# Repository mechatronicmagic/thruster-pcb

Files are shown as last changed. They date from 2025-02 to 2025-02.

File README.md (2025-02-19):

- [Repository Info](#orgcf761ff)
- [Images](#orga1b146e)
- [Schematic](#org2f8730d)
- [PCB](#orgee0fed7)
- [Bill of Materials](#org8738594)
- [Development](#org028dfc6)

    <!-- This file is generated automatically from metadata -->
    <!-- File edits may be overwritten! -->

# Repository Info

-   Project Name: thruster-pcb
-   Synopsis:
-   Documentation Version: 1.0.0
-   Pcb Version: 1.0
-   Enclosure Version: 1.0
-   Supplemental BOM Version: 1.0
-   Release Date: 2025-02-19
-   Creation Date: 2025-01-04
-   Kicad Version: 7.0.11
-   License: GPL-3.0h
-   URL: <https://github.com/mechatronicmagic/thruster-pcb>
-   Author: Peter Polidoro
-   Email: peter@polidoro.io
-   Copyright: 2025 Mechatronic Magic
-   References:
    -   [Servo Control](https://en.wikipedia.org/wiki/Servo_control)
    -   [SB2264MG Servo](https://www.savoxusa.com/products/savsb2264mg-low-profile-hv-brushless-servo)
    -   [PCA9685](https://www.nxp.com/products/power-management/lighting-driver-and-controller-ics/led-drivers/16-channel-12-bit-pwm-fm-plus-ic-bus-led-driver:PCA9685)
    -   [nRF52840 Express](https://www.adafruit.com/product/4062)

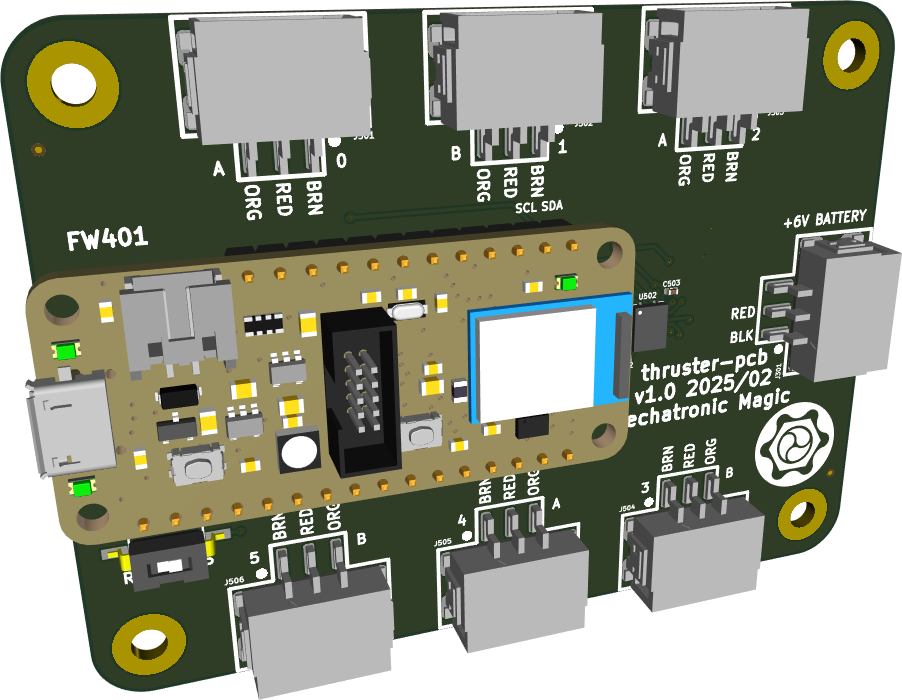
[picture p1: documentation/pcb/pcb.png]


# Images

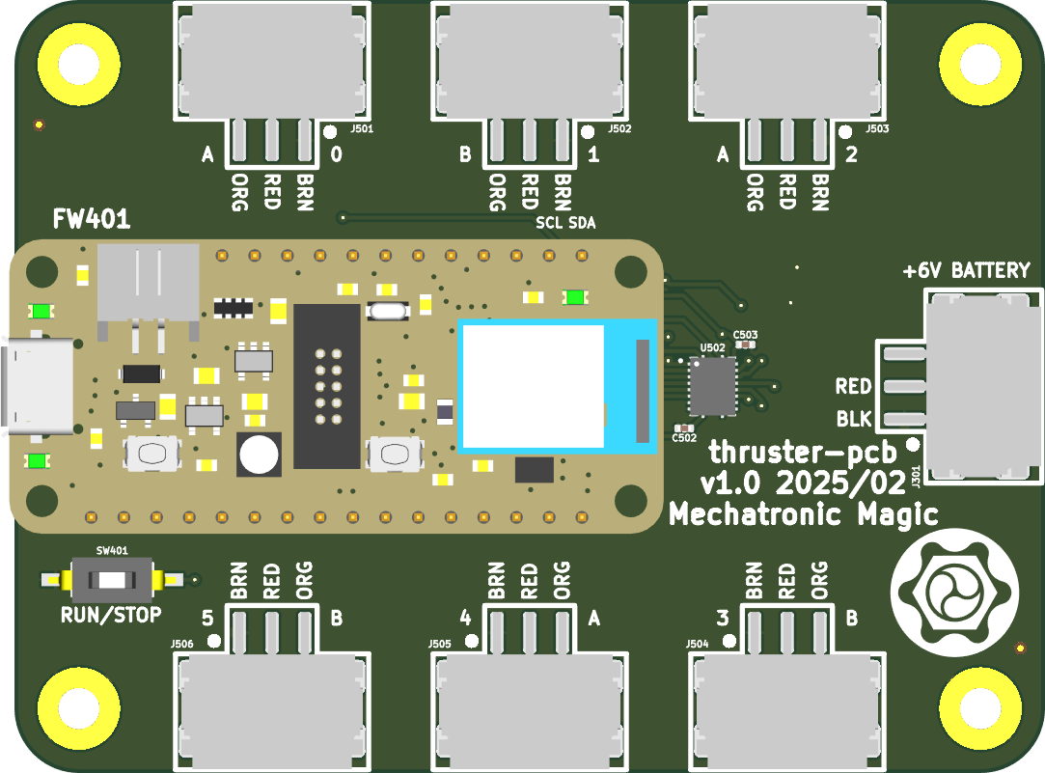
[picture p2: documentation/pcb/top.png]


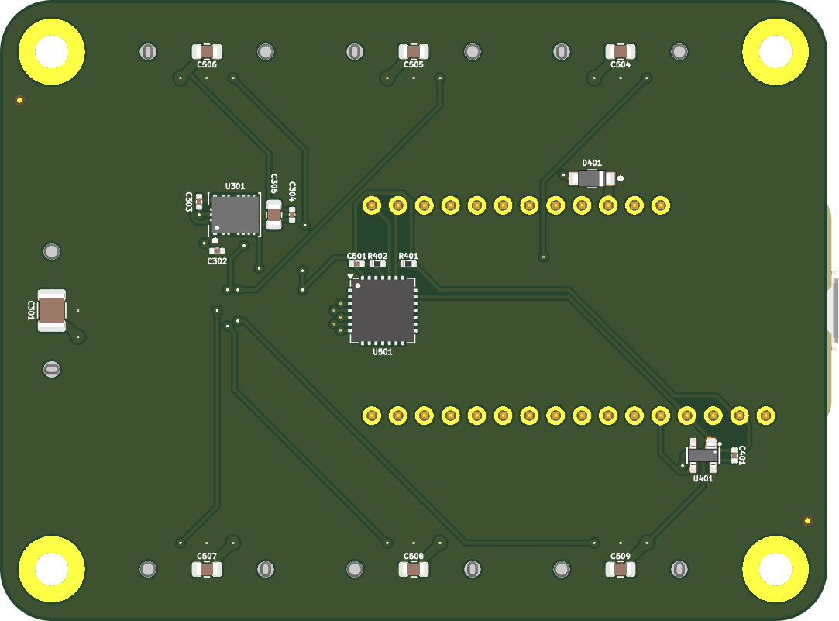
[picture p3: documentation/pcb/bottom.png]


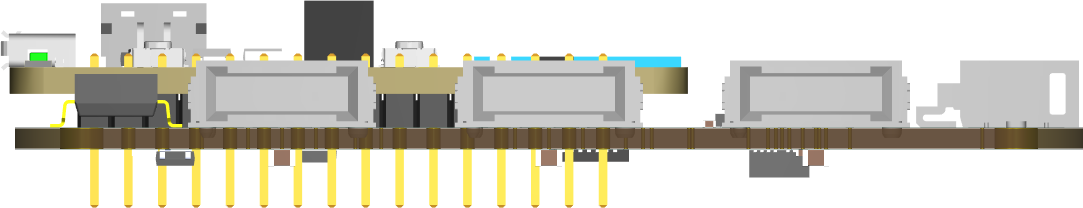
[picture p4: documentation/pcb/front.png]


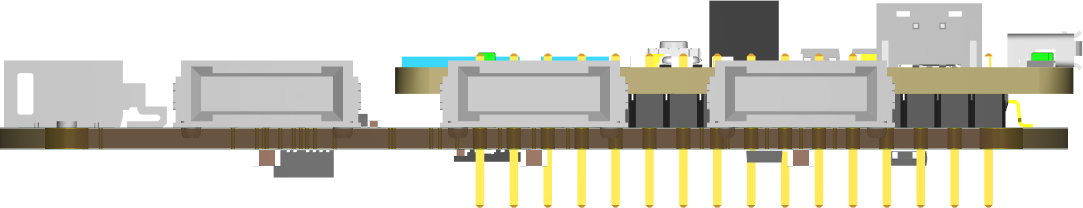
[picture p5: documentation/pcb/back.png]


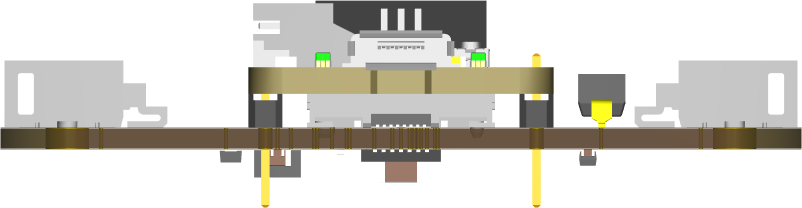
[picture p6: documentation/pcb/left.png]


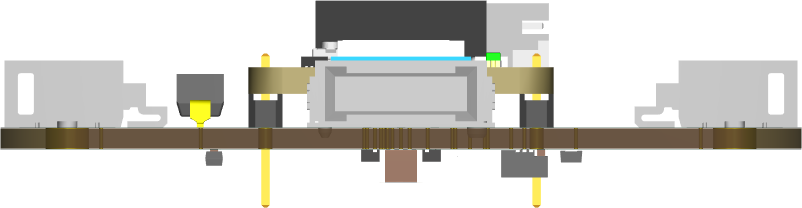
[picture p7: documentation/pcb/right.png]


# Schematic

[./documentation/schematic/thruster-pcb.pdf](./documentation/schematic/thruster-pcb.pdf)











# PCB











# Bill of Materials

## Board

| Item | Synopsis | Manufacturer Part Number | Manufacturer | Quantity | Reference(s) | Package |
|---- |--- |--- |--- |--- |--- |--- |
| 1 | 50V 3.3uF | FS32X335K500EGG | PSA(Prosperity Dielectrics) | 1 | C301 | 1210 |
| 2 | CAP CER 0.1UF 100V X5R | GRM155R62A104KE14D | Murata Electronics | 5 | C302 C401 C501 C502 C503 | 0402 |
| 3 | CAP CER 1UF 25V X5R | GRT155R61E105KE01D | Murata Electronics | 2 | C303 C304 | 0402 |
| 4 | CAP CER 47UF 10V X5R | CGA0805X5R476M100MT | HRE | 7 | C305 C504 C505 C506 C507 C508 C509 | 0805 |
| 5 | DIODE SCHOTTKY 20V 1A | MBR120VLSFT1G | onsemi | 1 | D401 | SOD-123FL |
| 6 | MAXIBR M 03POS RA A SMT BK | 284052-E | TE Connectivity | 7 | J301 J501 J502 J503 J504 J505 J506 | |
| 7 | RES SMD 1.8K OHM 5% 100mW | ERJ2GEJ182X | PANASONIC | 2 | R401 R402 | 0402 |
| 8 | 1 Digit SPST 24V 25mA DIP | EM-01KP | Korean Hroparts Elec | 1 | SW401 | SMD,2.5x6mm |
| 9 | DC-DC 5V 600mA Output 3-65V Input | TPSM365R6V5RDNR | Texas Instruments | 1 | U301 | QFN-11(3.5x4.5) |
| 10 | IC SWITCH DEBOUNCER | MAX6816EUS+T | Analog Devices Inc./Maxim Integrated | 1 | U401 | SOT-143 |
| 11 | IC LED DRVR LIN PWM 25MA | PCA9685BS,118 | NXP Semicon | 1 | U501 | SOT-788-1 |
| 12 | IC TRANSLTR BIDIRECTIONAL | TXS0108ERGYR | Texas Instruments | 1 | U502 | VQFN-20-EP(3.7x4.7) |

## Supplemental

| Item | Synopsis | Manufacturer Part Number | Manufacturer | Quantity | Cost  | Total |
|---- |--- |--- |--- |--- |----- |----- |
| 1 | Adafruit Feather nRF52840 Express | 4062 | adafruit | 1 | 24.95 | 24.95 |
| 2 | NiMH Battery (6V, 2700mAh, 2-Pos TJC8 Power Connector [MH-FC], 6-1) | 3100-0006-0001 | servocity | 1 | 14.99 | 14.99 |
| | Supplemental BOM Version: 1.0 | | | | Total | 39.94 |

# Development

## Install Guix

[Install Guix](https://guix.gnu.org/manual/en/html_node/Binary-Installation.html)

## Generate Output from KiCad

### Remove previous versions

```sh
rm -rf ./documentation/3dmodels/* && rm -rf ./documentation/bom/* && rm -rf ./documentation/fabrication/* && rm -rf ./documentation/pcb/* && rm -rf ./documentation/schematic/*pcb
```

### Images

1.  3D Viewer

    Output directory: ../documentation/pcb
    
    -   pcb.png
    -   top.png
    -   bottom.png
    -   front.png
    -   back.png
    -   left.png
    -   right.png

2.  Trim

        make trimmed-images

3.  Schematic PDF

    File -> Plot
    
    Output directory: ../documentation/schematic
    
    Plot All Pages
    
    -   Output format PDF
    -   Page Size = Schematic size
    -   Plot drawing sheet
    -   Output mode = Color
    -   Color theme = KiCad Default
    -   Default line width = 0.006 in

4.  Schematic SVG

    File -> Plot
    
    Output directory: ../documentation/schematic
    
    Plot All Pages
    
    -   Output format SVG
    -   Page Size = Schematic size
    -   Plot drawing sheet
    -   Output mode = Color
    -   Color theme = Solarized Light
    -   Default line width = 0.012 in

5.  PCB SVG

    Add Edge.Cuts, holes, and dimensions to User.Drawings
    
    File -> Plot
    
    Output directory: ../documentation/pcb
    
    -   Plot format SVG
    -   Include Layers
        -   User.Drawings
        -   F.Silkscreen
        -   B.Silkscreen
        -   F.Fab
        -   B.Fab
    -   Plot on All Layers
        -   Edge.Cuts
    -   Plot footprint values
    -   Plot reference designators
    -   SVG Options
        -   Precision = 4
        -   Output mode = color
    
        make cropped-svg

### Fabrication Files

1.  Gerbers

    File -> Fabrication Outputs -> Gerbers (.gbr)
    
    Output directory: ../documentation/fabrication/gerbers
    
    Include Layers:
    
    -   F.Cu
    -   F.Paste
    -   F.Silks
    -   F.Mask
    -   F.Fab
    -   B.Cu
    -   B.Paste
    -   B.Silks
    -   B.Mask
    -   B.Fab
    -   Edge.Cuts - (contain the board outline/cutouts.)
    -   In1.Cu, In2.Cu … - (needed for 4/6 layer designs.)
    
    Options:
    
    -   Select Plot reference designators, otherwise designators will not appear on silkscreen layers.
    -   Select Check zone fills before plotting
    -   Select Use Protel filename extensions, this is recommended as JLCPCB prefers Protel filename extensions.
    -   Select Subtract soldermask from silkscreen, this ensures no silkscreen on pads.
    -   Coordinate format 4.6 unit mm

2.  Drill and Map Files

    Output directory: ../documentation/fabrication/gerbers
    
    Options:
    
    -   Excellon drill file format
    -   Check Use alternate drill mode for "Oval Holes Drill Mode".
    -   Check Absolute for "Drill Origin".
    -   Check Millimeters for "Drill Units".
    -   Check Decimal format for "Zeros Format".
    -   Gerber X2 map file format
    
    Zip gerber files
    
        zip ./documentation/fabrication/gerbers.zip ./documentation/fabrication/gerbers/*

3.  BOM

    Generate BOM from schematic editor using blank command line to create bom xml file.

4.  POS

    File -> Fabrication Outputs -> Component Placement (.pos)
    
    Output directory: ../documentation/fabrication/
    
    Settings:
    
    -   Format = CSV
    -   Units = Millimeters
    -   Files = Single file for board
    -   Do not use drill/place file origin
    
    Modify pos files:
    
    -   Ref -> Designator
    -   PosX -> Mid X
    -   PosY -> Mid Y
    -   Rot -> Rotation
    -   Side -> Layer

5.  Step

    File -> Export -> Step
    
    Output directory: ../documentation/3dmodels/pcb.step
    
    -   Drill/place file origin
    -   Overwrite old file
    -   Standard Board outline chaining tolerance

## Edit metadata.org

    make metadata-edits

## Tangle metadata.org

    make metadata

## Edit project

    make kicad-edits
    exit

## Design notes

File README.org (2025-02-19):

# This file is generated automatically from metadata
# File edits may be overwritten!
- Project Name: thruster-pcb
- Synopsis: 
- Documentation Version: 1.0.0
- Pcb Version: 1.0
- Enclosure Version: 1.0
- Supplemental BOM Version: 1.0
- Release Date: 2025-02-19
- Creation Date: 2025-01-04
- Kicad Version: 7.0.11
- License: GPL-3.0h
- URL: https://github.com/mechatronicmagic/thruster-pcb
- Author: Peter Polidoro
- Email: peter@polidoro.io
- Copyright: 2025 Mechatronic Magic
- References:
  - [[https://en.wikipedia.org/wiki/Servo_control][Servo Control]]
  - [[https://www.savoxusa.com/products/savsb2264mg-low-profile-hv-brushless-servo][SB2264MG Servo]]
  - [[https://www.nxp.com/products/power-management/lighting-driver-and-controller-ics/led-drivers/16-channel-12-bit-pwm-fm-plus-ic-bus-led-driver:PCA9685][PCA9685]]
  - [[https://www.adafruit.com/product/4062][nRF52840 Express]]



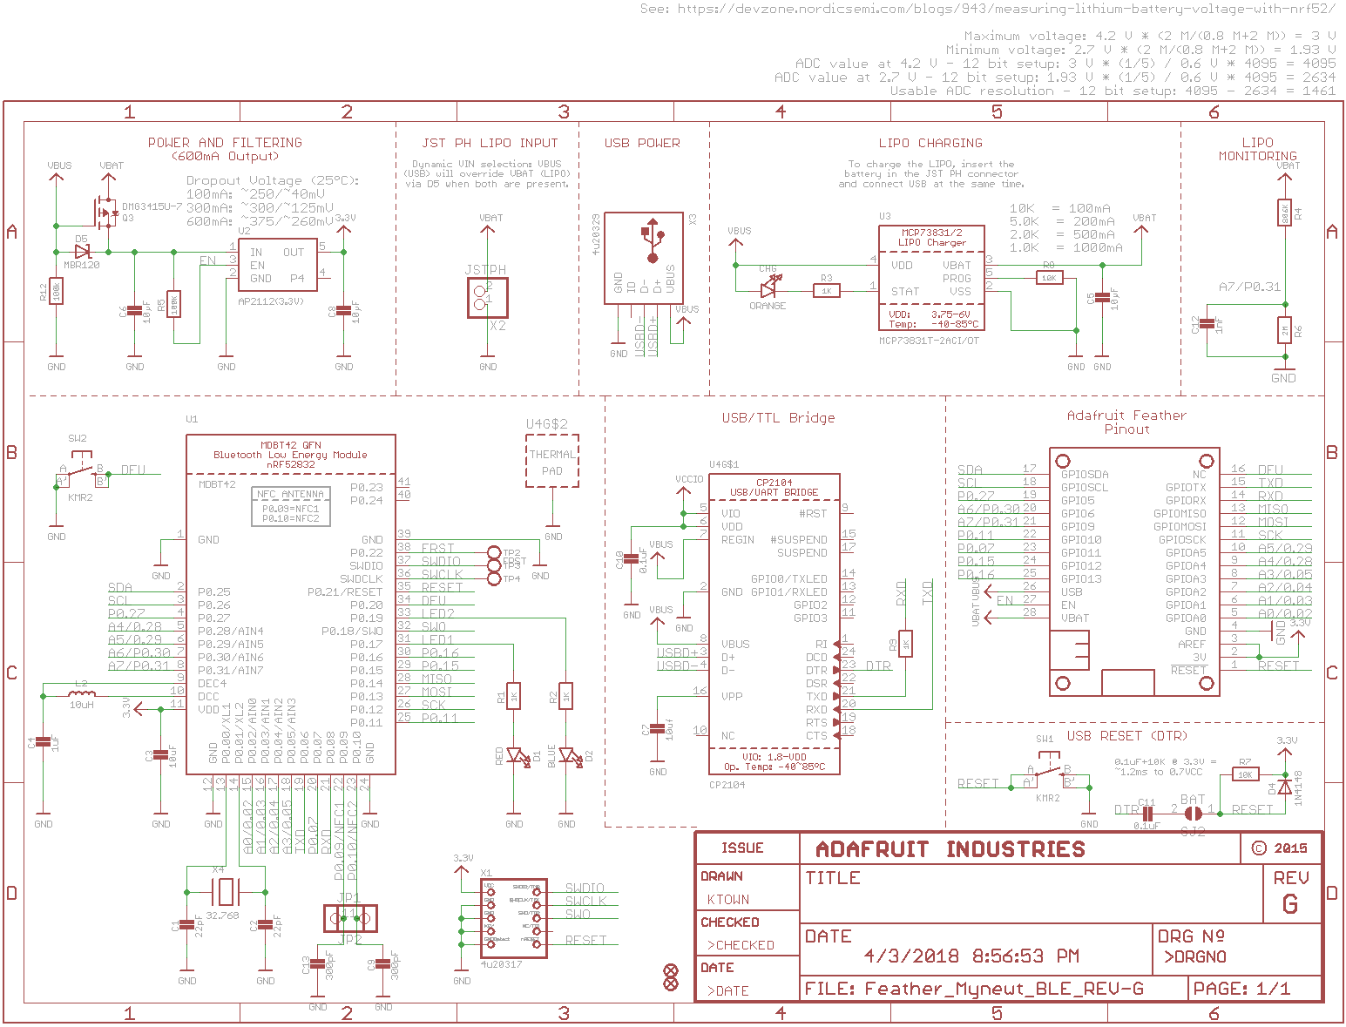
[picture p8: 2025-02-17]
documentation/reference/nrf52-schematic.png

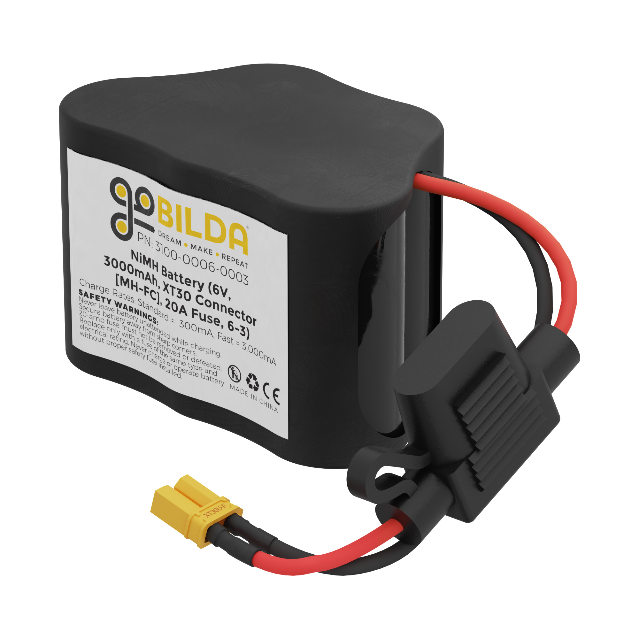
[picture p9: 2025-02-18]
documentation/reference/battery-xt30.jpg

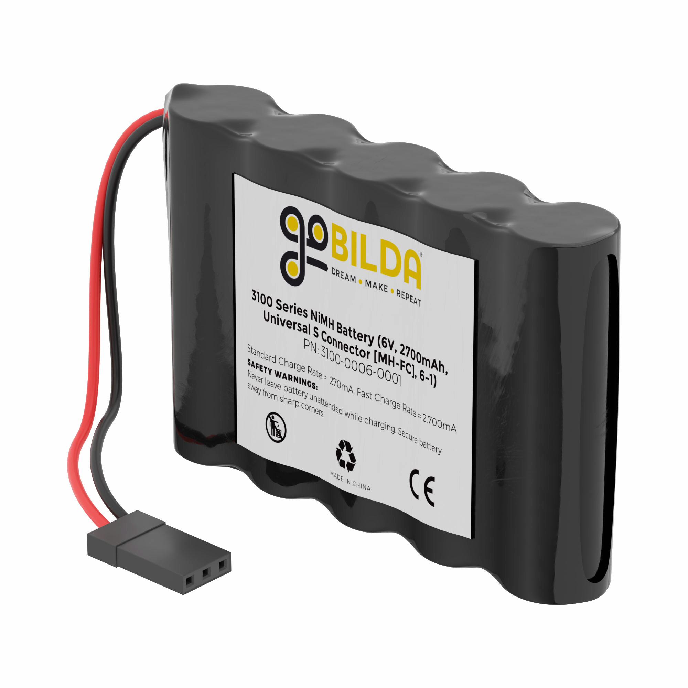
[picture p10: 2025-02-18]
documentation/reference/battery-tjc8.jpg

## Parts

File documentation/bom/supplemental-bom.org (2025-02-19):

#+OPTIONS: toc:nil title:nil num:nil ^:nil
#+LATEX_HEADER: \usepackage{adjustbox}
#+LATEX_HEADER: \usepackage[margin=2cm]{geometry}
* Supplemental BOM
- Project Name: thruster-pcb
- Synopsis: 
- Release Date: 2025-02-19
- URL: https://github.com/mechatronicmagic/thruster-pcb
- Author: Peter Polidoro
- Email: peter@polidoro.io
#+BEGIN_TABLE
#+LATEX: \adjustbox{max width=\linewidth}{
#+ATTR_LATEX: :center nil
| Item | Synopsis                                                            | Manufacturer Part Number | Manufacturer | Quantity |  Cost | Total |
|------+---------------------------------------------------------------------+--------------------------+--------------+----------+-------+-------|
|    1 | Adafruit Feather nRF52840 Express                                   |                     4062 | adafruit     |        1 | 24.95 | 24.95 |
|    2 | NiMH Battery (6V, 2700mAh, 2-Pos TJC8 Power Connector [MH-FC], 6-1) |           3100-0006-0001 | servocity    |        1 | 14.99 | 14.99 |
|------+---------------------------------------------------------------------+--------------------------+--------------+----------+-------+-------|
|      | Supplemental BOM Version: 1.0              |                          |              |          | Total | 39.94 |
#+TBLFM: @2$1..@>>$1=@#-1::$7=$5*$6;%0.2f::@>$7=vsum(@2..@-1);%0.2f
#+LATEX: }
#+END_TABLE

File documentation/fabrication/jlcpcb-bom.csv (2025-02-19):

Comment | Designator | Footprint | LCSC
50V 3.3uF | C301 | 1210 | C1021610
CAP CER 0.1UF 100V X5R | C302 C401 C501 C502 C503 | 0402 | C162178
CAP CER 1UF 25V X5R | C303 C304 | 0402 | C711085
CAP CER 47UF 10V X5R | C305 C504 C505 C506 C507 C508 C509 | 0805 | C6119904
DIODE SCHOTTKY 20V 1A | D401 | SOD-123FL | C223608
MAXIBR M 03POS RA A SMT BK | J301 J501 J502 J503 J504 J505 J506 |  | C17355078
RES SMD 1.8K OHM 5% 100mW | R401 R402 | 0402 | C409855
1 Digit SPST 24V 25mA DIP | SW401 | SMD,2.5x6mm | C129077
DC-DC 5V 600mA Output 3-65V Input | U301 | QFN-11(3.5x4.5) | C19078014
IC SWITCH DEBOUNCER | U401 | SOT-143 | C41637
IC LED DRVR LIN PWM 25MA | U501 | SOT-788-1 | C5191634
IC TRANSLTR BIDIRECTIONAL | U502 | VQFN-20-EP(3.7x4.7) | C90706

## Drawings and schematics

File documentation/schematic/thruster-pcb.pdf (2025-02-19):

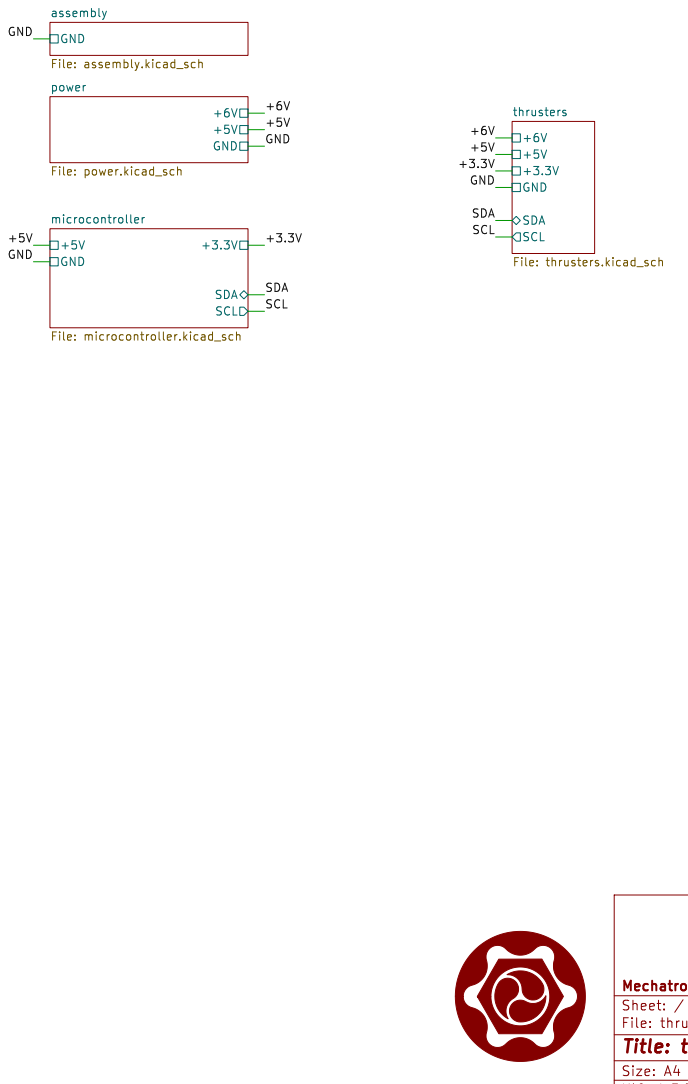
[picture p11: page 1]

power File: power.kicad_sch GND

Id: 1/5 Title: thruster-pcb

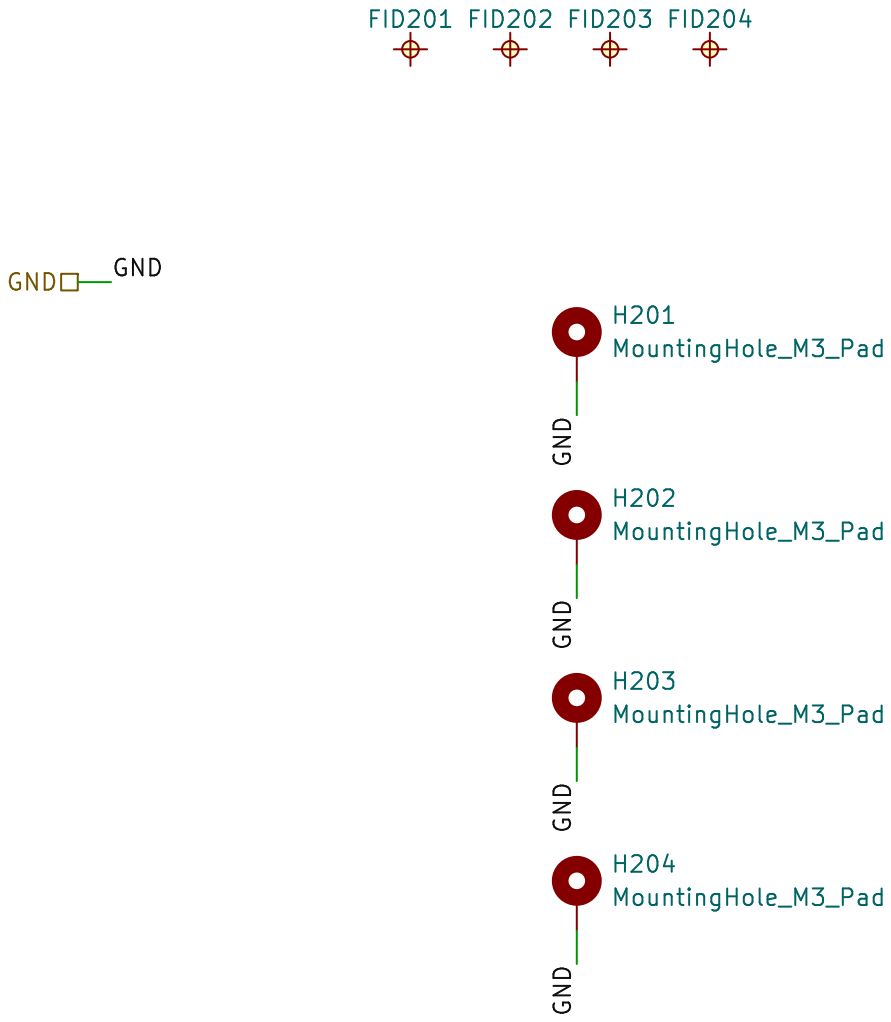
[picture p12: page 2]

Id: 2/5 Title: thruster-pcb

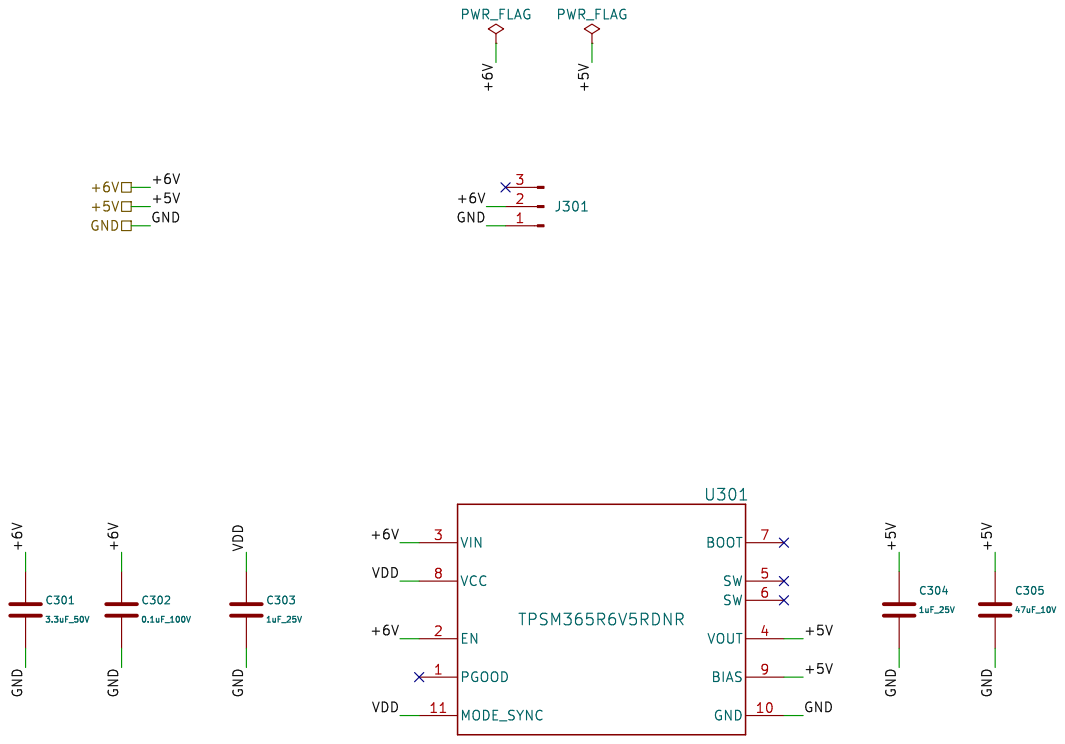
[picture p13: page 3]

Id: 3/5 Title: thruster-pcb

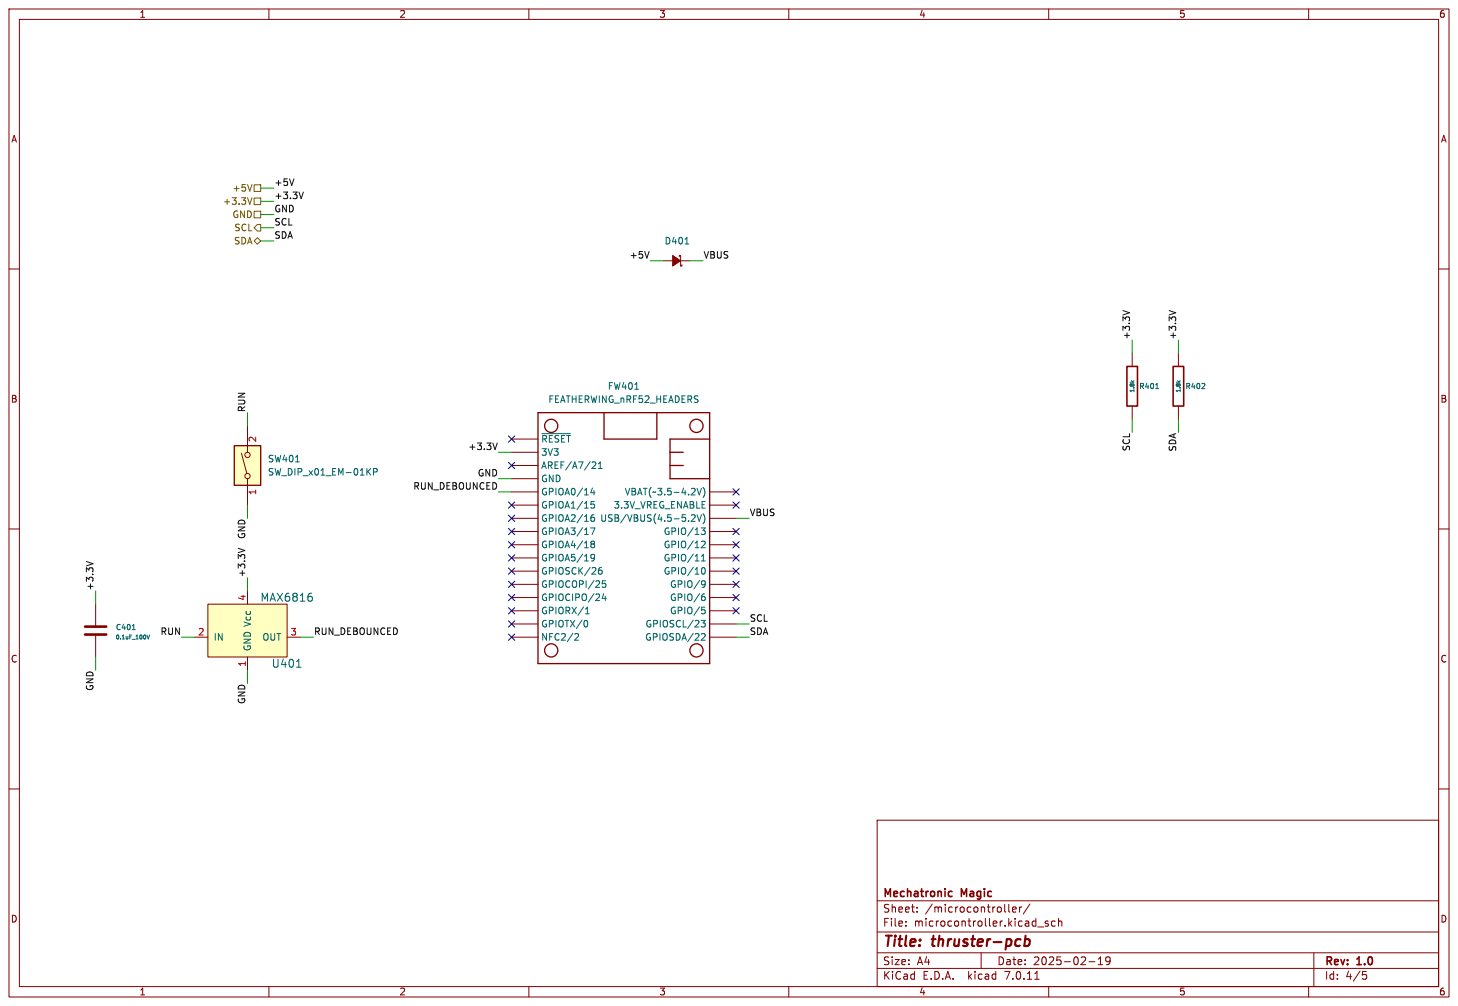
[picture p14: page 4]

Id: 4/5 Title: thruster-pcb

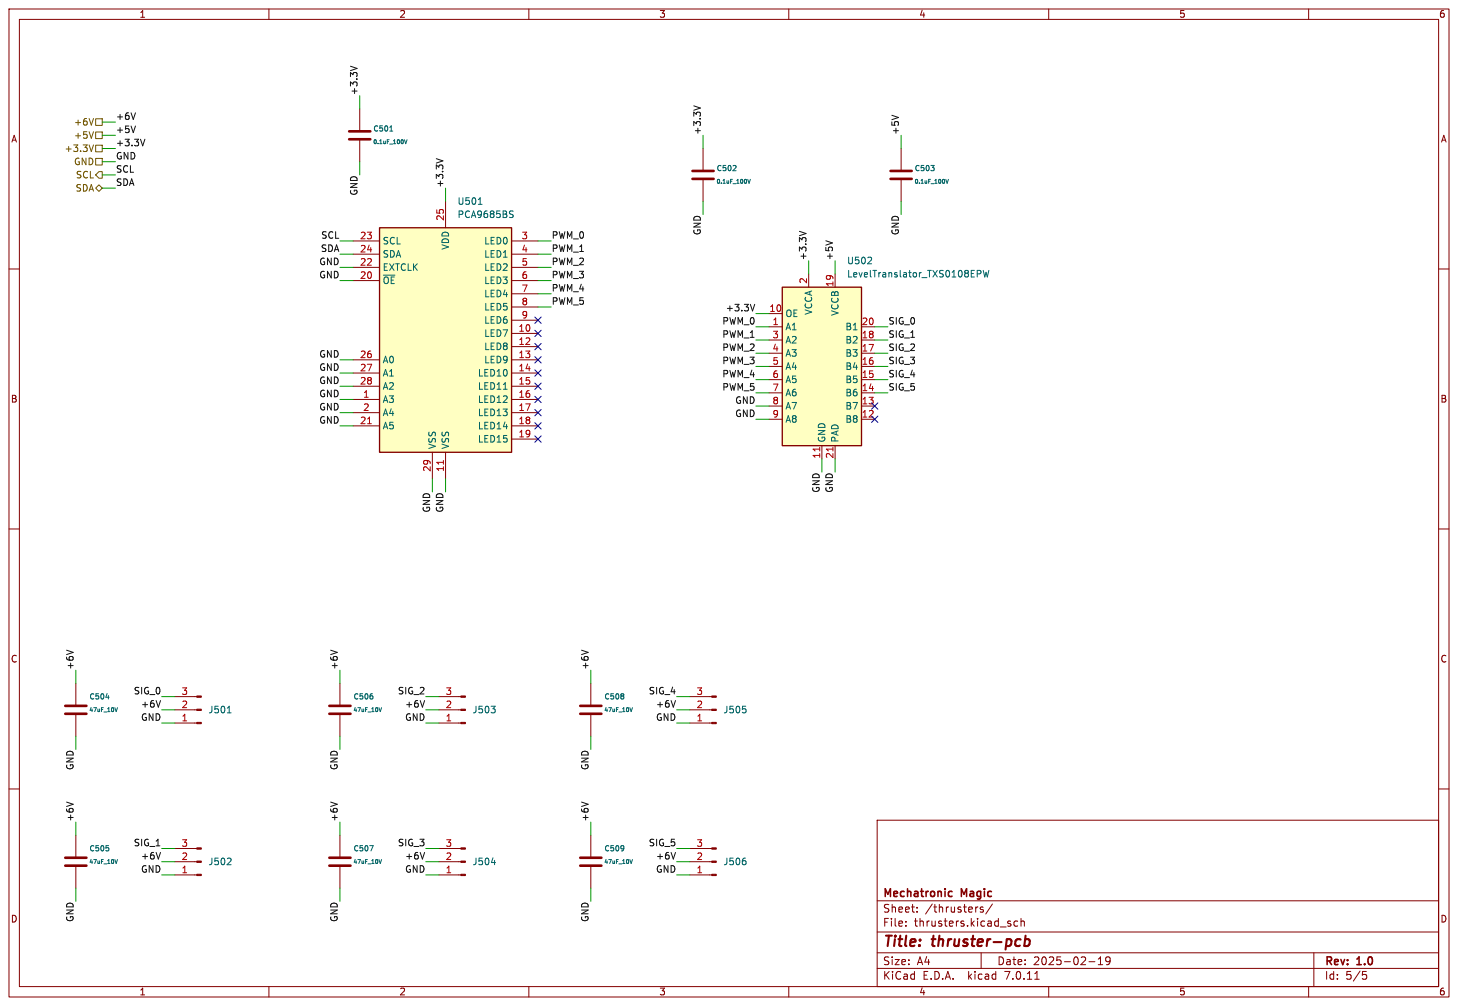
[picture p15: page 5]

Id: 5/5 Title: thruster-pcb

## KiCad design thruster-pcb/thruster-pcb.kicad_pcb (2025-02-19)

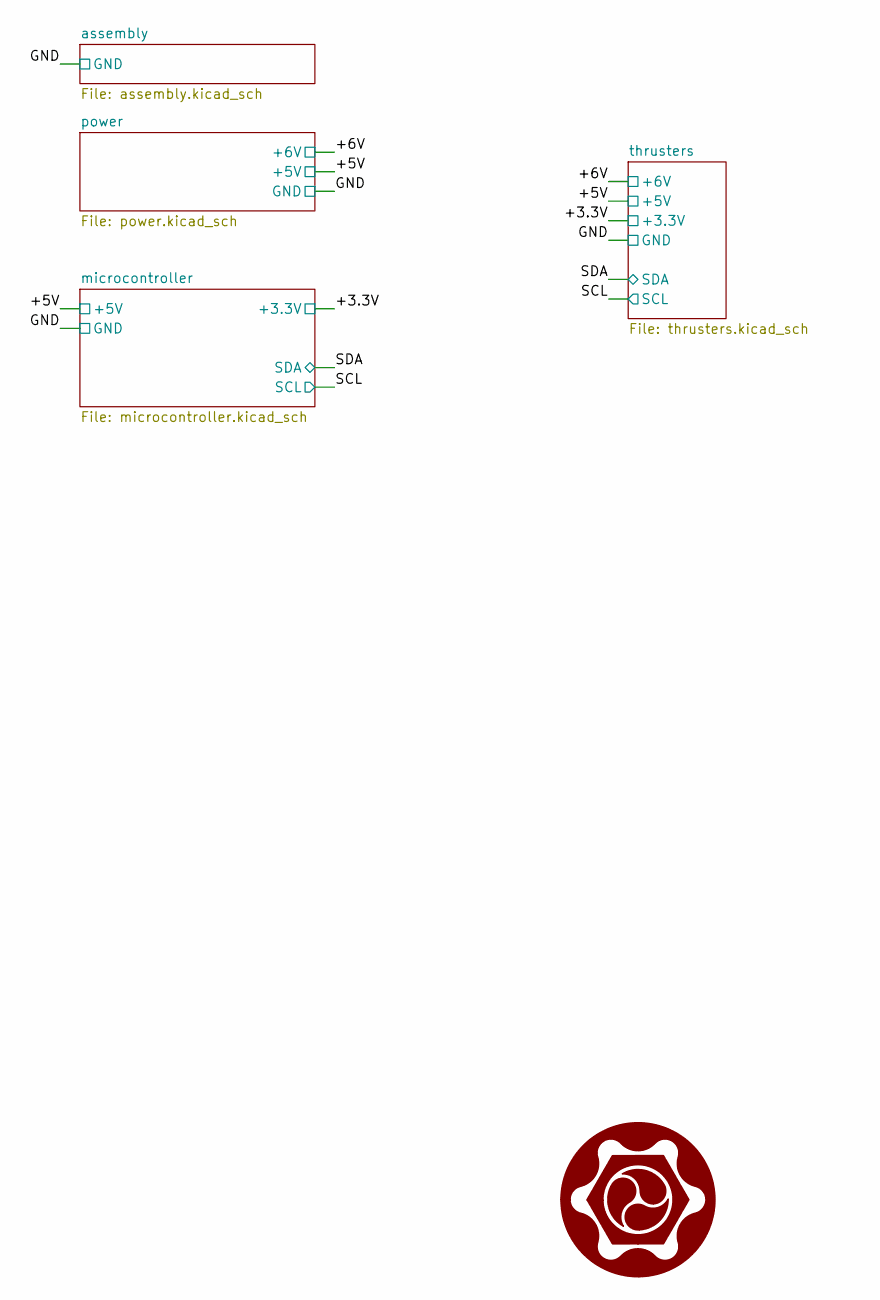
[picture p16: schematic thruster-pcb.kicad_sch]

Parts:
G101: LOGO-10mm; logo-white-fg-black-bg-10mm

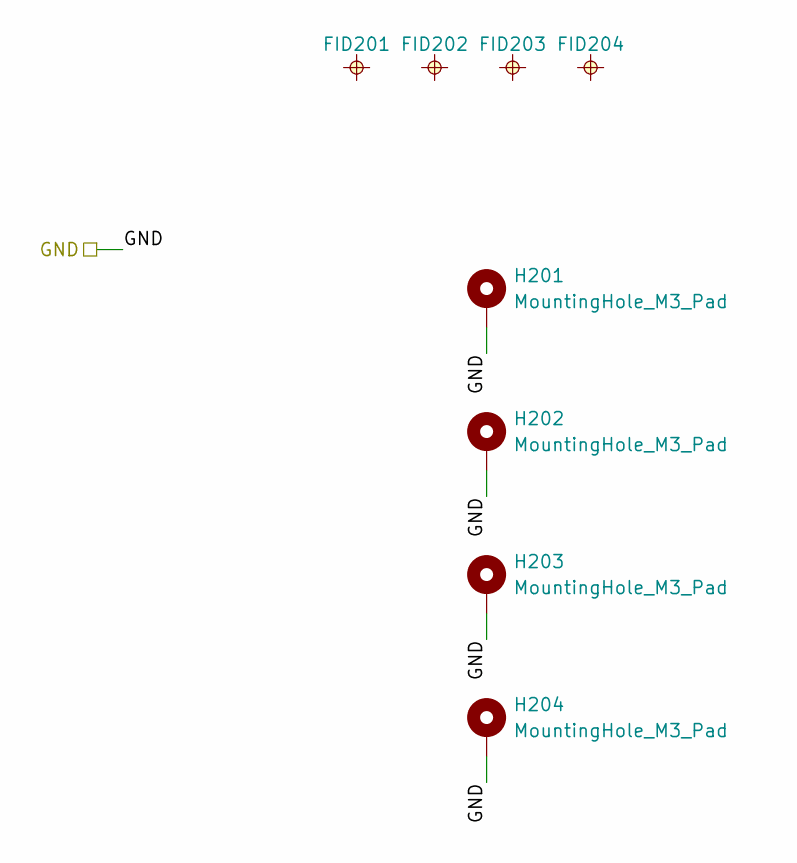
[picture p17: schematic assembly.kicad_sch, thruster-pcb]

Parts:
FID201, FID202, FID203, FID204: FIDUCIAL_0.5mm_MASK1mm; FIDUCIAL_0.5mm_Mask1mm
H201, H202, H203, H204: MountingHole_M3_Pad; MountingHole_3.2mm_M3_Pad

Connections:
/GND: H201.1, H202.1, H203.1, H204.1; also elsewhere on the board

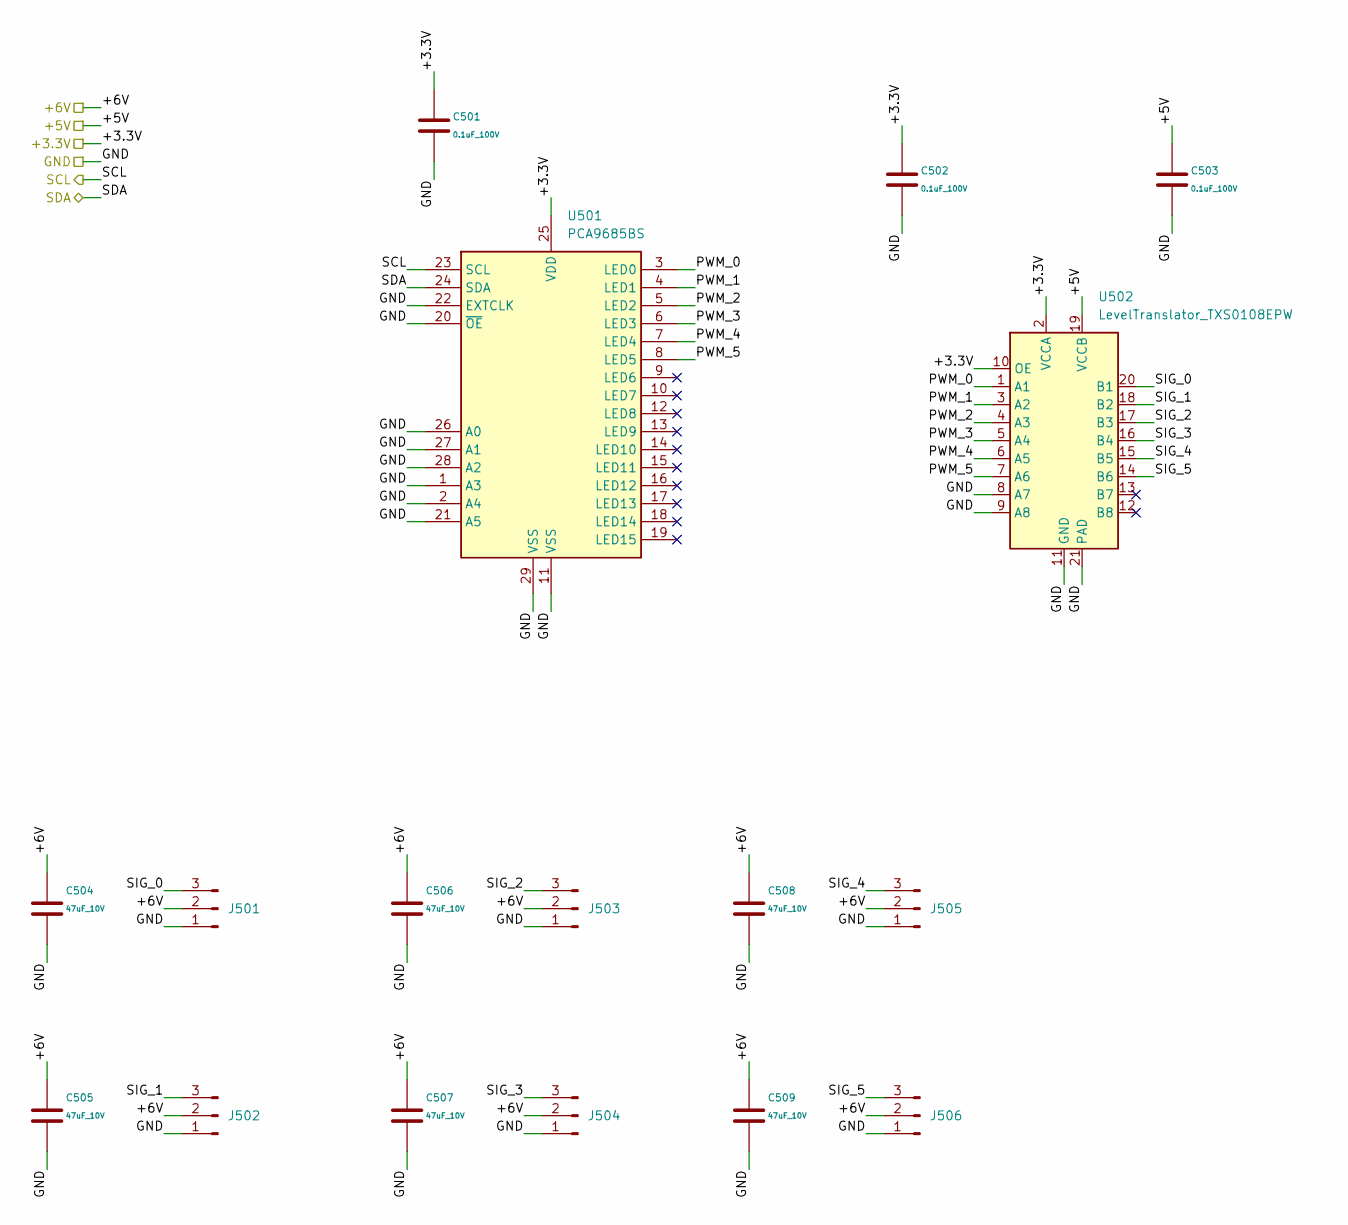
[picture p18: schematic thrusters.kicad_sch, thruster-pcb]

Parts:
C501, C502, C503: 0.1uF_100V; C_0402_1005Metric; Manufacturer Part Number GRM155R62A104KE14D; LCSC C162178
C504, C505, C506, C507, C508, C509: 47uF_10V; C_0805_2012Metric; Manufacturer Part Number CGA0805X5R476M100MT; LCSC C6119904
J501, J502, J503, J504, J505, J506: Conn_TERM_HDR_01x03_Pin_3.5mm_Horizontal; Connector_Header_1x03_P2.54mm_Horizontal_SMD_284052-E; Manufacturer Part Number 284052-E; LCSC C17355078
U501: PCA9685BS; QFN-28-1EP_6x6mm_P0.65mm_EP4.25x4.25mm; Manufacturer Part Number PCA9685BS,118; LCSC C5191634
U502: LevelTranslator_TXS0108EPW; IC_TXS0108ERGYR; Manufacturer Part Number TXS0108ERGYR; LCSC C90706

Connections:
/+3.3V: C501.1, C502.1, U501.25 (VDD), U502.2 (VCCA), U502.10 (OE); also elsewhere on the board
/+5V: C503.1, U502.19 (VCCB); also elsewhere on the board
/+6V: C504.1, C505.1, C506.1, C507.1, C508.1, C509.1, J501.2, J502.2, J503.2, J504.2, J505.2, J506.2; also elsewhere on the board
/GND: C501.2, C502.2, C503.2, C504.2, C505.2, C506.2, C507.2, C508.2, C509.2, J501.1, J502.1, J503.1, J504.1, J505.1, J506.1, U501.1 (A3), U501.2 (A4), U501.11 (VSS), U501.20 (~OE), U501.21 (A5), U501.22 (EXTCLK), U501.26 (A0), U501.27 (A1), U501.28 (A2), U501.29 (VSS), U502.8 (A7), U502.9 (A8), U502.11 (GND), U502.21 (PAD); also elsewhere on the board
/SCL: U501.23 (SCL); also elsewhere on the board
/SDA: U501.24 (SDA); also elsewhere on the board
/thrusters/PWM_0: U501.3 (LED0), U502.1 (A1)
/thrusters/PWM_1: U501.4 (LED1), U502.3 (A2)
/thrusters/PWM_2: U501.5 (LED2), U502.4 (A3)
/thrusters/PWM_3: U501.6 (LED3), U502.5 (A4)
/thrusters/PWM_4: U501.7 (LED4), U502.6 (A5)
/thrusters/PWM_5: U501.8 (LED5), U502.7 (A6)
/thrusters/SIG_0: J501.3, U502.20 (B1)
/thrusters/SIG_1: J502.3, U502.18 (B2)
/thrusters/SIG_2: J503.3, U502.17 (B3)
/thrusters/SIG_3: J504.3, U502.16 (B4)
/thrusters/SIG_4: J505.3, U502.15 (B5)
/thrusters/SIG_5: J506.3, U502.14 (B6)

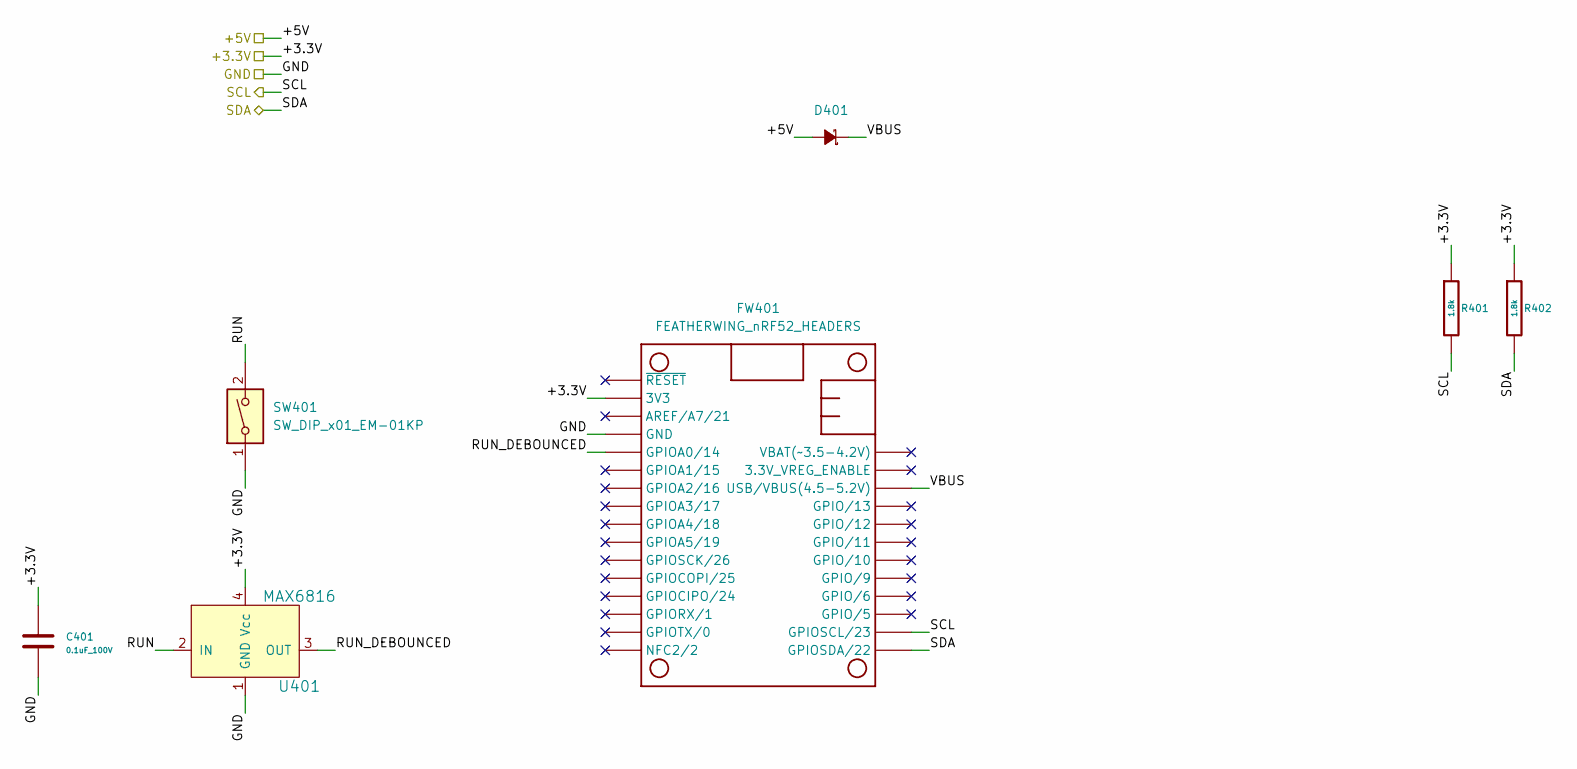
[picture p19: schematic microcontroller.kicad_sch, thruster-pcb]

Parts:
C401: 0.1uF_100V; C_0402_1005Metric; Manufacturer Part Number GRM155R62A104KE14D; LCSC C162178
D401: D_SCHOTTKY_20V_1A; SOD-123FL; Manufacturer Part Number MBR120VLSFT1G; LCSC C223608
FW401: FEATHERWING_nRF52_HEADERS; FEATHERWING_HEADERS; Manufacturer Part Number 4062
R401, R402: 1.8k; R_0402_1005Metric; Manufacturer Part Number ERJ2GEJ182X; LCSC C409855
SW401: SW_DIP_x01_EM-01KP; SW_SPST_EM-01KP; Manufacturer Part Number EM-01KP; LCSC C129077
U401: MAX6816; SOT192P237X122-4N; Manufacturer Part Number MAX6816EUS+T; LCSC C41637

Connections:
/+3.3V: C401.1, FW401.2 (3V3), R401.1, R402.1, U401.4 (Vcc); also elsewhere on the board
/+5V: D401.2 (A); also elsewhere on the board
/GND: C401.2, FW401.4 (GND), SW401.1, U401.1 (GND); also elsewhere on the board
/SCL: FW401.18 (GPIOSCL/23), R401.2; also elsewhere on the board
/SDA: FW401.17 (GPIOSDA/22), R402.2; also elsewhere on the board
/microcontroller/RUN: SW401.2, U401.2 (IN)
/microcontroller/RUN_DEBOUNCED: FW401.5 (GPIOA0/14), U401.3 (OUT)
/microcontroller/VBUS: D401.1 (K), FW401.26 (USB/VBUS(4.5-5.2V))

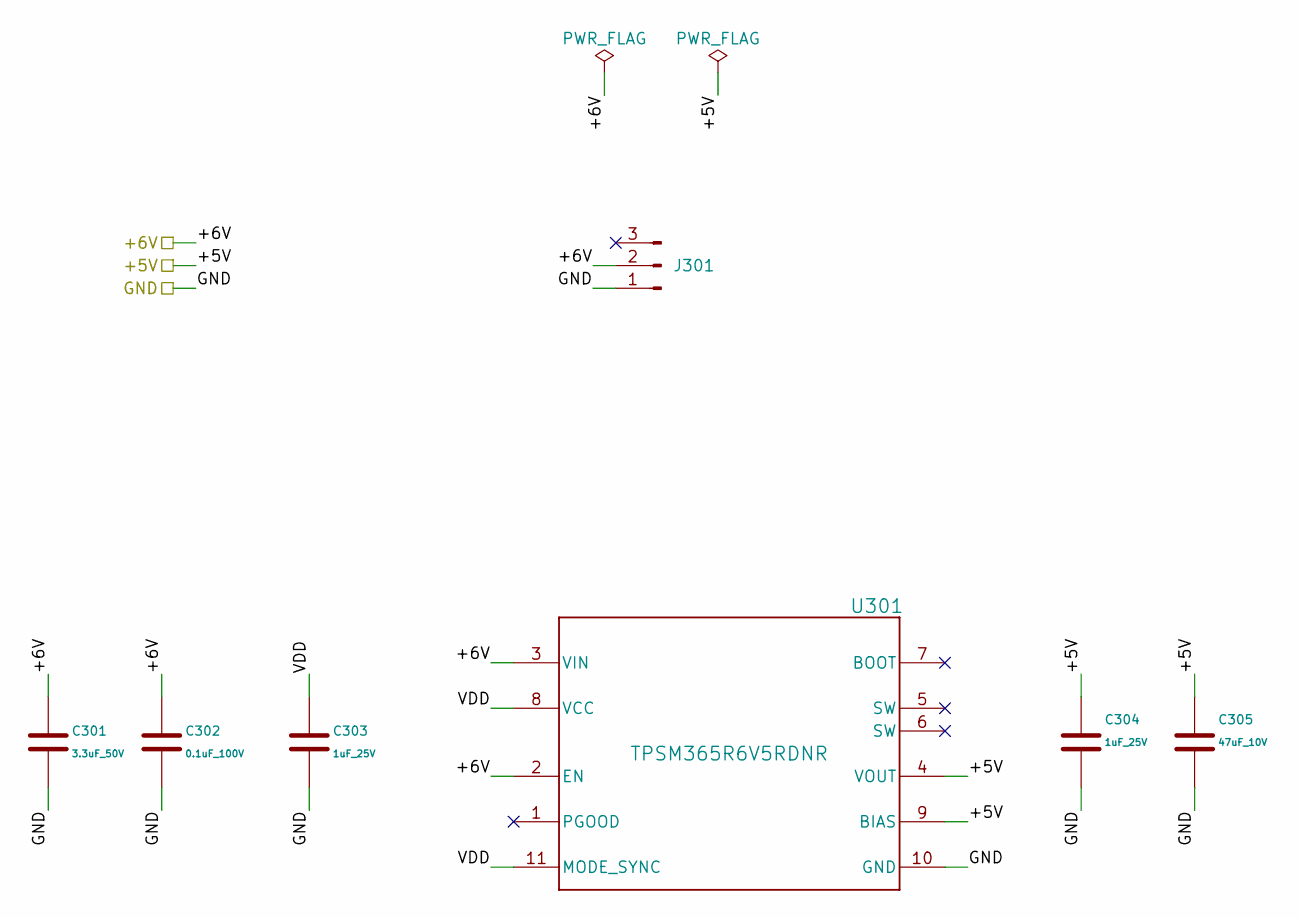
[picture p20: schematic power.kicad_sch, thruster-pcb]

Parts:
C301: 3.3uF_50V; C_1210_3225Metric; Manufacturer Part Number FS32X335K500EGG; LCSC C1021610
C302: 0.1uF_100V; C_0402_1005Metric; Manufacturer Part Number GRM155R62A104KE14D; LCSC C162178
C303, C304: 1uF_25V; C_0402_1005Metric; Manufacturer Part Number GRT155R61E105KE01D; LCSC C711085
C305: 47uF_10V; C_0805_2012Metric; Manufacturer Part Number CGA0805X5R476M100MT; LCSC C6119904
J301: Conn_TERM_HDR_01x03_Pin_3.5mm_Horizontal; Connector_Header_1x03_P2.54mm_Horizontal_SMD_284052-E; Manufacturer Part Number 284052-E; LCSC C17355078
U301: TPSM365R6V5RDNR; RDN0011A-MFG; Manufacturer Part Number TPSM365R6V5RDNR; LCSC C19078014

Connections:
/+5V: C304.1, C305.1, U301.4 (VOUT), U301.9 (BIAS); also elsewhere on the board
/+6V: C301.1, C302.1, J301.2, U301.2 (EN), U301.3 (VIN); also elsewhere on the board
/GND: C301.2, C302.2, C303.2, C304.2, C305.2, J301.1, U301.10 (GND); also elsewhere on the board
/power/VDD: C303.1, U301.8 (VCC), U301.11 (MODE_SYNC)

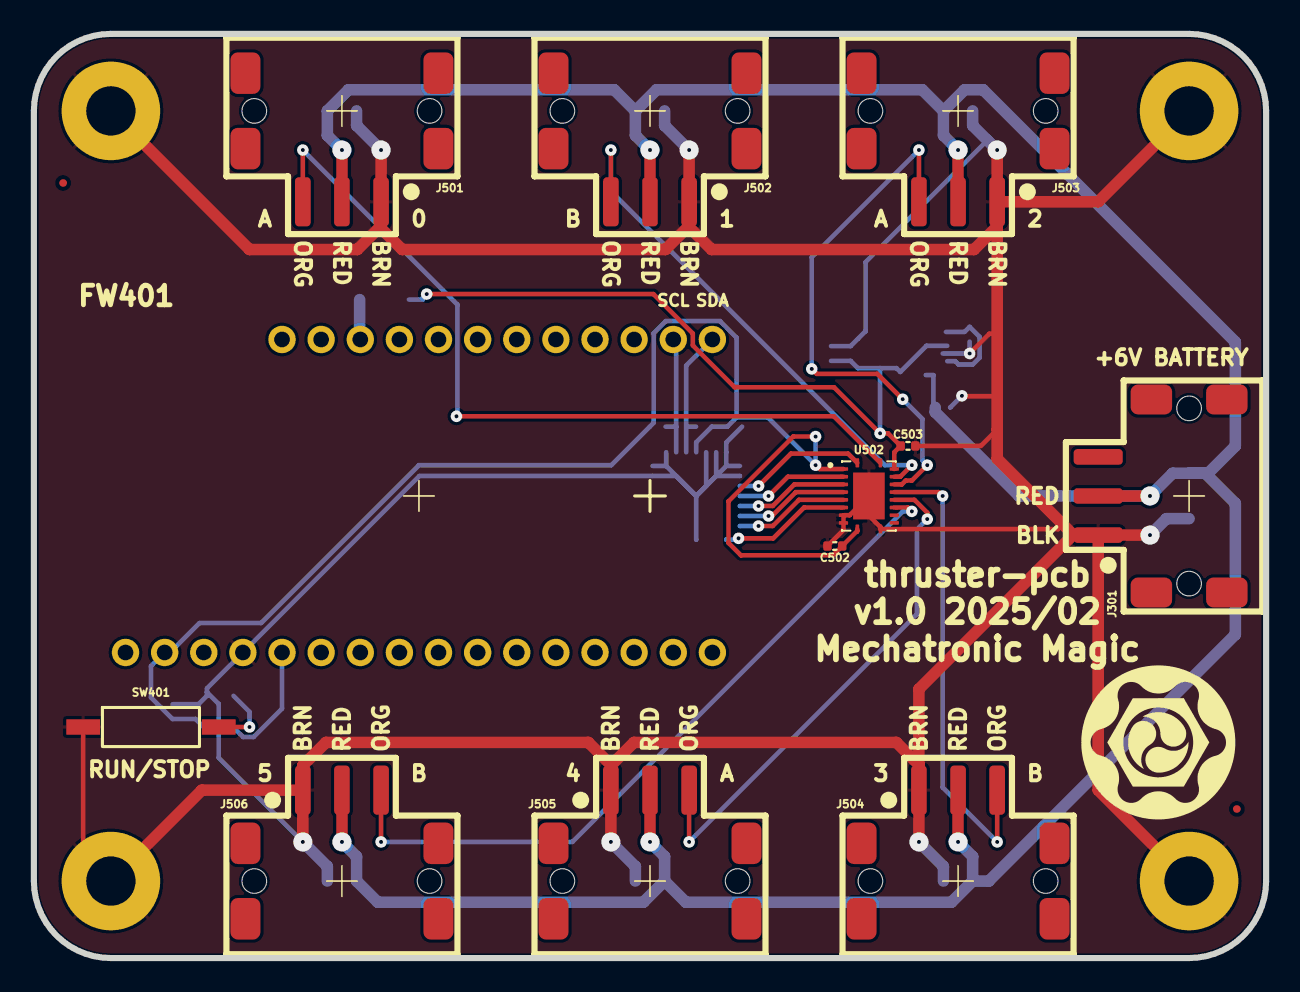
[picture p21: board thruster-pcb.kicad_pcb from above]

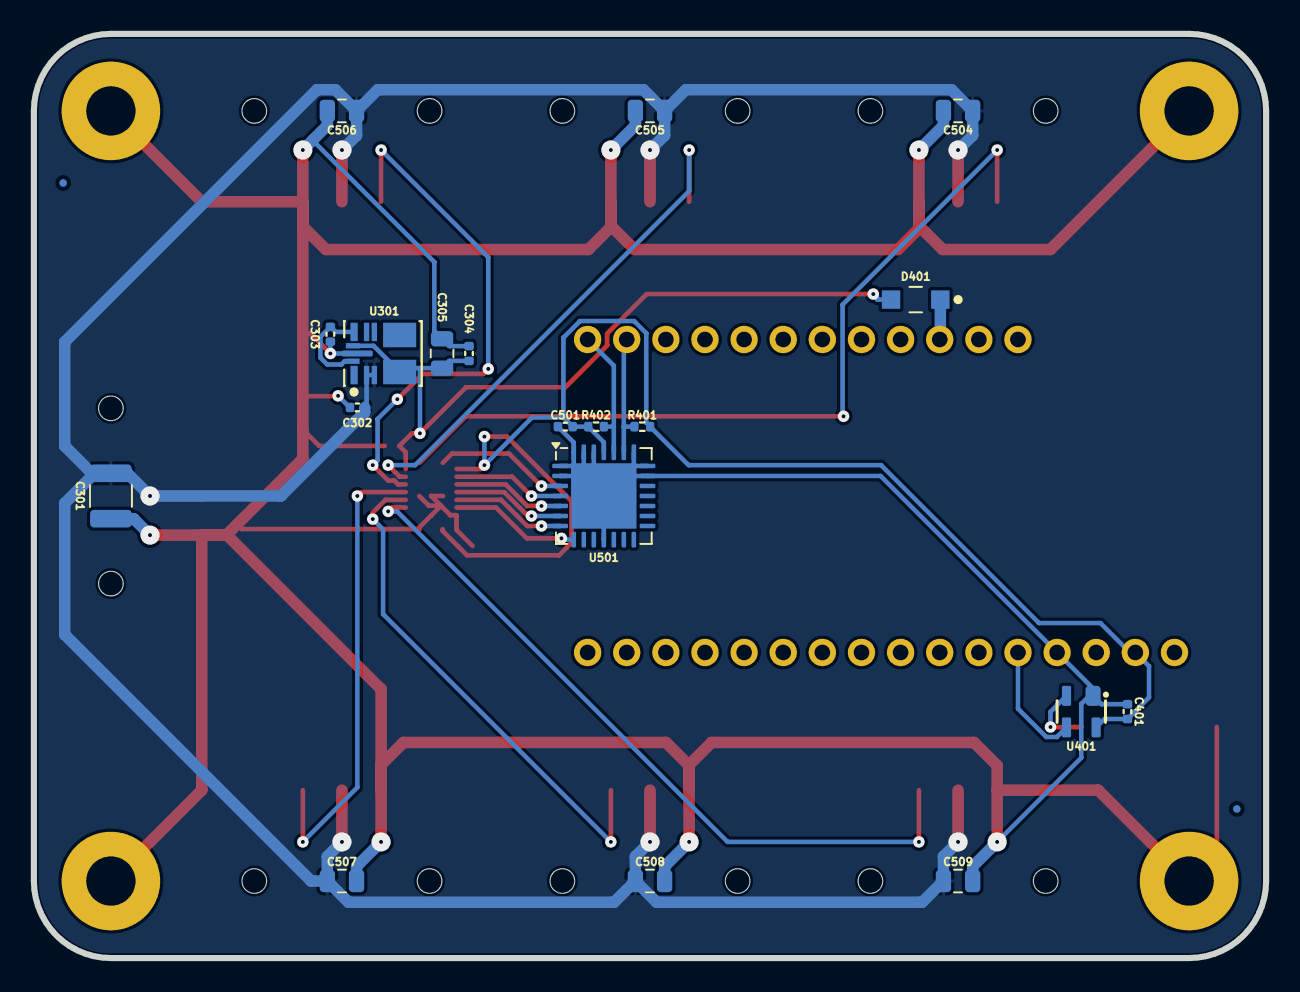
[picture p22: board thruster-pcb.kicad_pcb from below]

Board: 2 copper layers, 80.0 x 60.0 mm, 40 parts (21 on the bottom side), 22 nets.

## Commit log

2025-01-04 tmc5160-usb -> thruster-pcb
    [assembly.kicad_sch, power.kicad_sch, rp2040.kicad_sch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]
2025-01-04 Add reference files
    [assembly.kicad_sch, power.kicad_sch, rp2040.kicad_sch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]
2025-01-12 Add parts to schematic
    [thruster-pcb.kicad_sch]
2025-02-16 Use PCA9685 and nRF52
    [address.kicad_sch, assembly.kicad_sch, audio.kicad_sch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]
2025-02-17 Initial components
    [address.kicad_sch, audio.kicad_sch, microcontroller.kicad_sch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]
2025-02-17 Add sheets
    [microcontroller.kicad_sch, power.kicad_sch, thruster-pcb.kicad_sch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]
2025-02-18 Initial schematic and layout
    [assembly.kicad_sch, microcontroller.kicad_sch, power.kicad_sch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]
2025-02-19 Initial layout
    [assembly.kicad_sch, microcontroller.kicad_sch, power.kicad_sch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]
2025-02-19 Finished v1.0
    [assembly.kicad_sch, microcontroller.kicad_sch, power.kicad_sch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]
2025-02-19 Updated pcb
    [thruster-pcb.kicad_pcb]
2025-02-19 Updated supplemental-bom
2025-02-19 Add bom
    [jlcpcb-bom.csv]
